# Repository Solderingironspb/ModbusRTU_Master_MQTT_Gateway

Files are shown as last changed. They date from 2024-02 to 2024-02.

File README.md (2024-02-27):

# ModbusRTU_Master_MQTT_Gateway
Данное устройство выступает мастером сети ModbusRTU. Обменивается данными с подчиненными устройствами (до 247 устройств на линии RS485). Все данные дублируются по MQTT на сервер, где они могут обрабатываться, а также появится возможность с сервера управлять подчиненными устройствами. (При условии, что ты это все в силах сам запрограммировать, мой друг...).

### Описание:
Общение осуществляется по RS485. Согласно документации, длина линии может доходить до 1 км, а изоляция по RS485 достигает 3000 В. На этой линии могут находиться счетчики электрической энергии, промышленные холодильники, климатические камеры, кондиционеры, щиты управления чего-либо и много чего другого. ModbusRTU используется с 1979 года по сей день и промышленных устройств, поддерживающих этот протокол миллионы.

### Немного по технической части:
Основную задачу по работе с ModbusRTU берет на себя RISC-V микроконтроллер CH32V203F8P6. На нем заданы тайминги для правильной работы протокола и написана своя реализация ModbusRTU Master. Все написано на RVMSIS. Отличный, очень компактный камушек с двумя UART на борту. Единственный минус данного МК - он не имеет входа кварцевого резонатора, поэтому сильно задирать скорость UART не стал бы. Обычного 9600 - 115200 хватит. Пока тестирую на 9600. Работает без сбоев.
По части WIFI - здесь распаян WiFi модуль на базе однокристальной системы (SoC) ESP8266. Написано свое ПО для модуля, что оно работает в качестве WIFI MQTT шлюза. Общение с CH32V203F8P6 происходит через USART по самописному протоколу, которым я пользуюсь уже 3 года без сбоев.
Многие, кто в теме задаст очередной вопрос, почему всю работу не осуществить на ESP8266? Отвечаю: я не знаю на столько хорошо ES8266, чтоб доверить ей работу с прерываниями, таймерами и прочим. Система, по которой я работаю - обкатана годами. Менять пока не собираюсь.

### По корпусу:
Очень хотелось выпендриться и уместить все в корпус на DIN рейку и чтоб 1 модуль занимало всего лишь. Из за этого мы видим антенну, которая немного мешает подключать RS485 (GND), но опять же....как часто мы GND туда подцепляем?) На 80% устройств она отсутствует в принципе.
DCDC преобразователем, чтоб можно было питать устройство от 12-24В тоже пришлось пожертвовать, негде его там расположить внутри). Поэтому питание устройства от 5В. Защита от переполюсовки присутствует.
Не знал, как поступить с портом для программирования устройства. На лицевую сторону тяжело уже было вывести, поэтому ничего не оставалось, как сделать окошко в корпусе справа. Открыл - запрогал - закрыл.

### По дизайну:
Все в традициях нашего оборудования) Немного уродливо, зато с душой и относительно бюджетно 😁

### Ну и не забываем, что все делалось в домашних условиях)











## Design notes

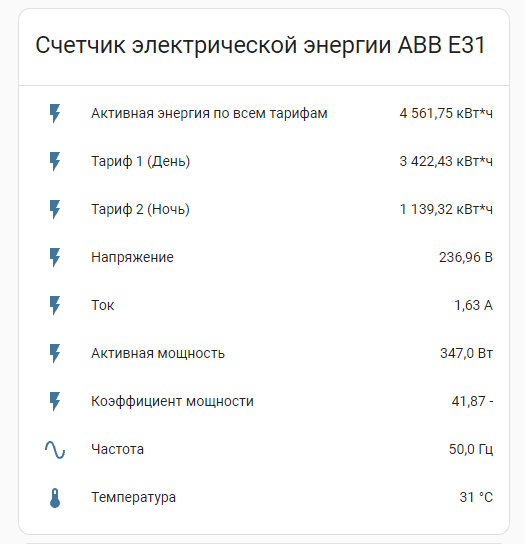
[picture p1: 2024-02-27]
Project1_Опрос_электросчетчика_ABB_E31/Снимок.PNG

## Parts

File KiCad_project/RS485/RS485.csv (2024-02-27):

Source: | Z:\KiCad_project\RS485\RS485\RS485.kicad_sch
Date: | 03.02.2024 23:45:19
Tool: | Eeschema 7.0.8
Generator: | C:\Program Files\KiCad\7.0\bin\scripting\plugins/bom_csv_grouped_by_value.py
Component Count: | 59
Collated Components:
Item | Qty | Reference(s) | Value | LibPart | Footprint | Datasheet | DNP
1 | 4 | C1, C5, C6, C8 | 100n | Device:C_Small | Capacitor_SMD:C_0603_1608Metric | ~
2 | 1 | C2 | 10uF | Device:C_Small | Capacitor_SMD:C_0805_2012Metric | ~
3 | 2 | C3, C4 | 5uF | Device:C_Small | Capacitor_SMD:C_0805_2012Metric | ~
4 | 2 | C7, C9 | 220pF | Device:C_Small | Capacitor_SMD:C_0805_2012Metric | ~
5 | 4 | C10, C11, C14, C15 | 47uF | Device:C_Polarized_Small | Capacitor_Tantalum_SMD:CP_EIA-3528-21_Kemet-B_Pad1.50x2.35mm_HandSolder | ~
6 | 3 | C12, C13, C16 | 100nF | Device:C_Small | Capacitor_SMD:C_0603_1608Metric | ~
7 | 1 | CA-IS3741LW1 | ~ | CA-IS374x:CA-IS3741LW | Package_SO:SOIC-16W_7.5x10.3mm_P1.27mm
8 | 1 | CH32V203F8P1 | ~ | CH32V:CH32V203F8P6 | Package_SO:SSOP-20_5.3x7.2mm_P0.65mm
9 | 1 | D1 | PSM712-LF-T7 | Device:D_TVS_Dual_AAC | Package_TO_SOT_SMD:SOT-23-3 | ~
10 | 1 | D2 | Tx2 | Device:LED | Diode_SMD:D_0805_2012Metric | ~
11 | 1 | D3 | Rx2 | Device:LED | Diode_SMD:D_0805_2012Metric | ~
12 | 1 | D4 | 10MQ100NPBF | Diode:B120-E3 | Diode_SMD:D_SMA | http://www.vishay.com/docs/88946/b120.pdf
13 | 1 | D5 | LED | Device:LED | Diode_SMD:D_0805_2012Metric | ~
14 | 1 | D6 | Rx1 | Device:LED | Diode_SMD:D_0805_2012Metric | ~
15 | 1 | D7 | Tx1 | Device:LED | Diode_SMD:D_0805_2012Metric | ~
16 | 1 | D8 | Wifi | Device:LED | Diode_SMD:D_0805_2012Metric | ~
17 | 2 | J1, J2 | Master/Slave | Connector:Conn_01x03_Pin | Connector_PinHeader_2.54mm:PinHeader_1x03_P2.54mm_Vertical | ~
18 | 1 | J3 | Debug | Connector:Conn_01x04_Pin | Connector_PinHeader_2.54mm:PinHeader_1x04_P2.54mm_Vertical | ~
19 | 1 | J4 | Conn_01x02_Pin | Connector:Conn_01x02_Pin |  | ~
20 | 1 | L1 | 22uH | Device:L_Small | Inductor_SMD:L_1210_3225Metric | ~
21 | 1 | PS1 | MornsunS0505SC | Converter_DCDC:MEE1S0505SC | Converter_DCDC:Converter_DCDC_Murata_MEE1SxxxxSC_THT | https://power.murata.com/pub/data/power/ncl/kdc_mee1.pdf
22 | 1 | Q1 | IRLML0060 | Transistor_FET:IRLML0030 | Package_TO_SOT_SMD:SOT-23 | https://www.infineon.com/dgdl/irlml0030pbf.pdf?fileId=5546d462533600a401535664773825df
23 | 1 | R1 | 240 | Device:R_Small | Resistor_SMD:R_0805_2012Metric | ~
24 | 2 | R2, R11 | 470R | Device:R_Small | Resistor_SMD:R_0805_2012Metric | ~
25 | 8 | R3, R7, R16, R17, R18, R19, R20, R21 | 10k | Device:R_Small | Resistor_SMD:R_0603_1608Metric | ~
26 | 2 | R4, R8 | 10R | Device:R_Small | Resistor_SMD:R_0805_2012Metric | ~
27 | 2 | R5, R9 | 100R | Device:R_Small | Resistor_SMD:R_0805_2012Metric | ~
28 | 6 | R6, R10, R12, R13, R14, R15 | 1k | Device:R_Small | Resistor_SMD:R_0603_1608Metric | ~
29 | 1 | SW1 | Reset | Switch:SW_MEC_5G | Button_Switch_SMD:SW_Push_1P1T_NO_CK_KSC6xxJ | http://www.apem.com/int/index.php?controller=attachment&id_attachment=488
30 | 1 | U1 | MAX485E | Interface_UART:MAX485E | Package_SO:SO-8_3.9x4.9mm_P1.27mm | https://datasheets.maximintegrated.com/en/ds/MAX1487E-MAX491E.pdf
31 | 2 | U2, U4 | AMS1117-3.3 | Regulator_Linear:AMS1117-3.3 | Package_TO_SOT_SMD:SOT-223-3_TabPin2 | http://www.advanced-monolithic.com/pdf/ds1117.pdf
32 | 1 | U3 | ESP-07 | RF_Module:ESP-07 | RF_Module:ESP-07 | http://wiki.ai-thinker.com/_media/esp8266/esp8266_series_modules_user_manual_v1.1.pdf

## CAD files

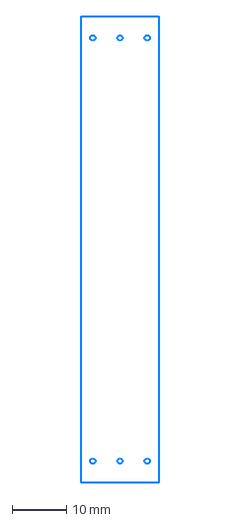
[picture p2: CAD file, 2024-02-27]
KiCad_project/RS485/KOMPAS3D/1.dxf
14.3 x 86.0 mm

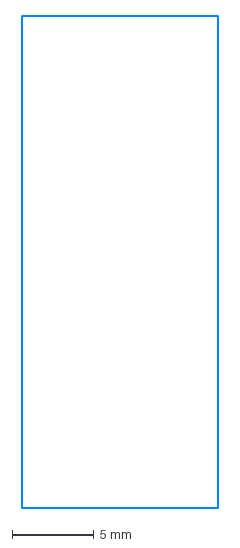
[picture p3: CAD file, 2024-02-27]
KiCad_project/RS485/KOMPAS3D/3.dxf
12.0 x 30.0 mm

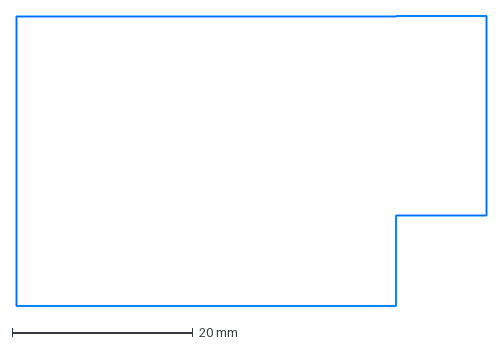
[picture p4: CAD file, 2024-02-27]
KiCad_project/RS485/KOMPAS3D/2.dxf
52.0 x 32.0 mm

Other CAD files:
KiCad_project/RS485/KOMPAS3D/1.dwg
KiCad_project/RS485/KOMPAS3D/2.dwg
KiCad_project/RS485/KOMPAS3D/3.dwg

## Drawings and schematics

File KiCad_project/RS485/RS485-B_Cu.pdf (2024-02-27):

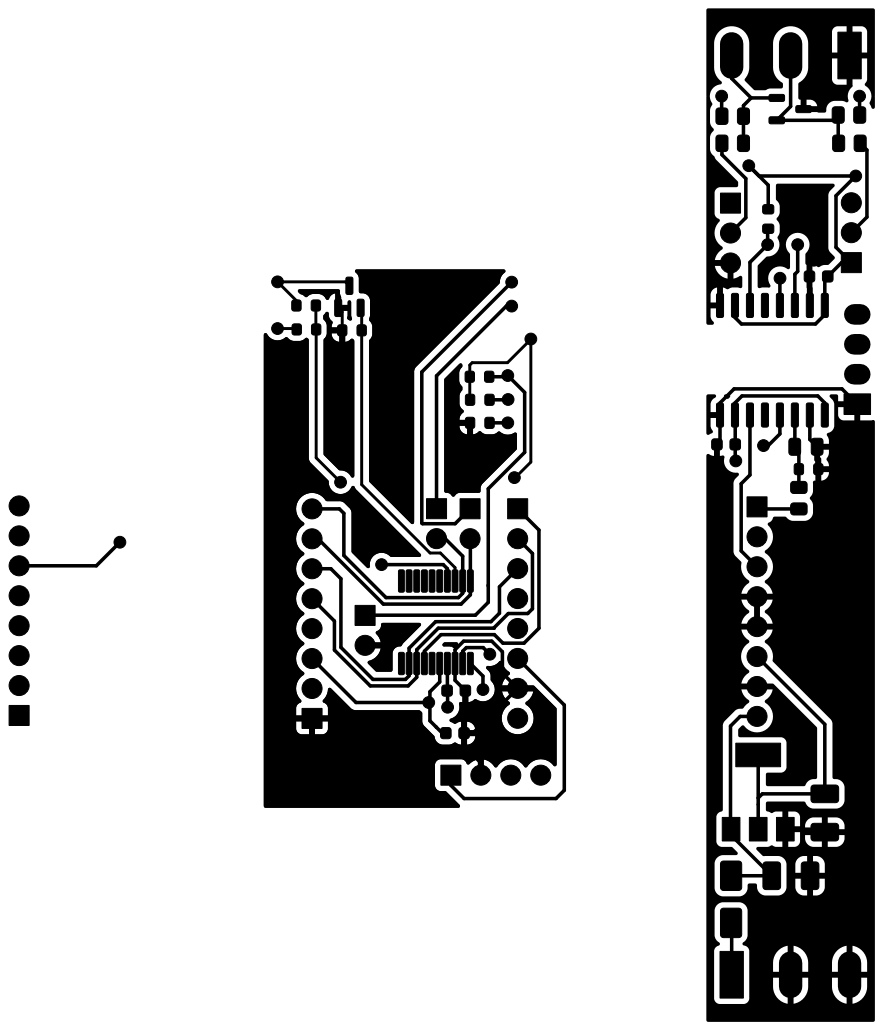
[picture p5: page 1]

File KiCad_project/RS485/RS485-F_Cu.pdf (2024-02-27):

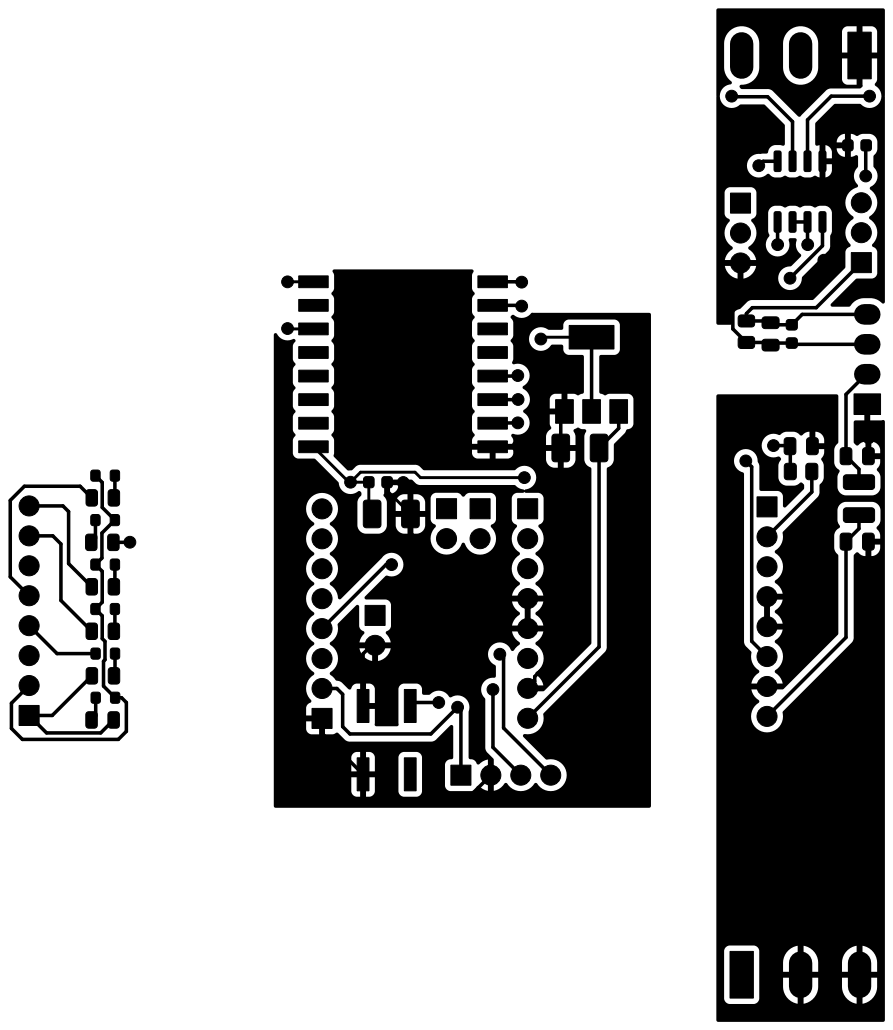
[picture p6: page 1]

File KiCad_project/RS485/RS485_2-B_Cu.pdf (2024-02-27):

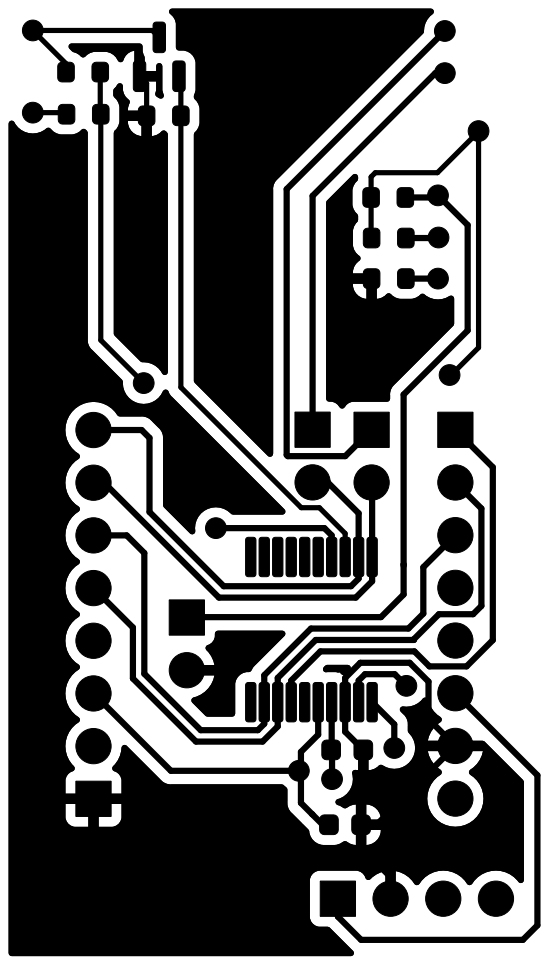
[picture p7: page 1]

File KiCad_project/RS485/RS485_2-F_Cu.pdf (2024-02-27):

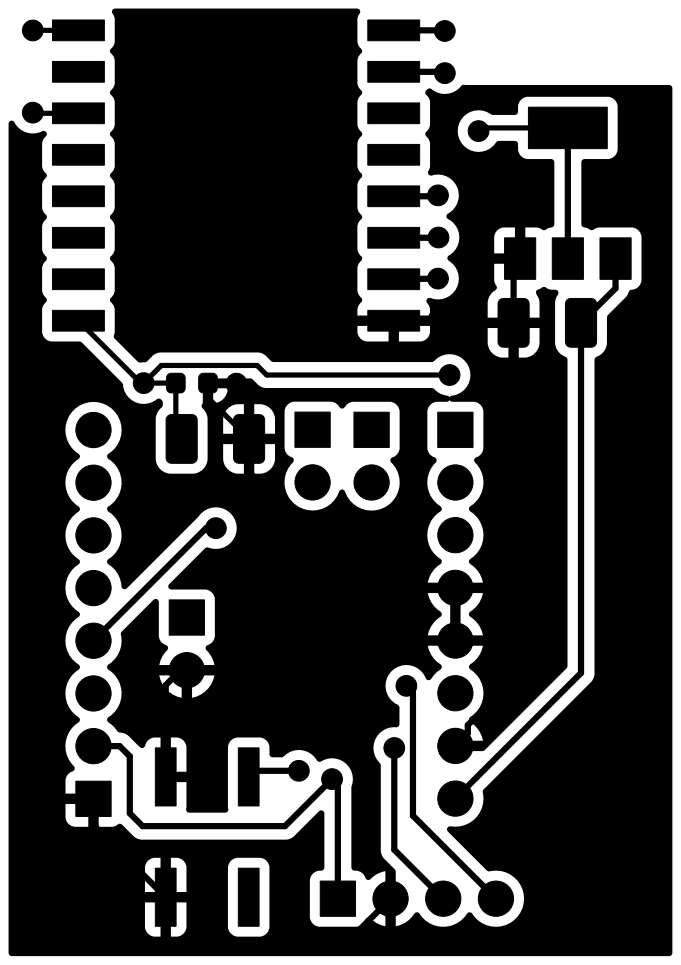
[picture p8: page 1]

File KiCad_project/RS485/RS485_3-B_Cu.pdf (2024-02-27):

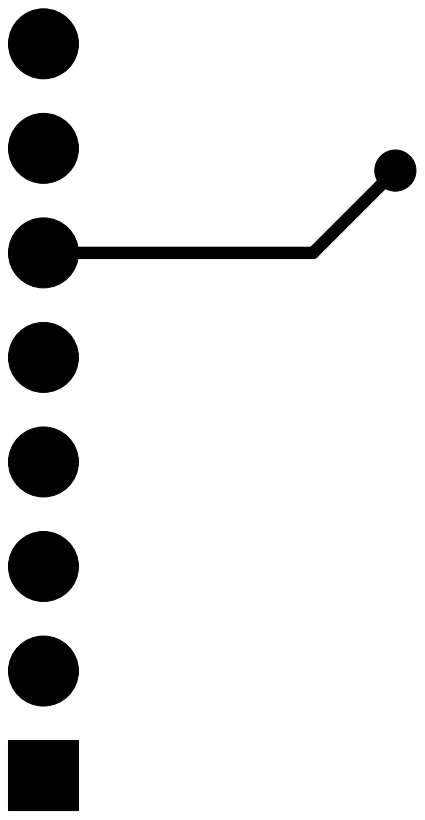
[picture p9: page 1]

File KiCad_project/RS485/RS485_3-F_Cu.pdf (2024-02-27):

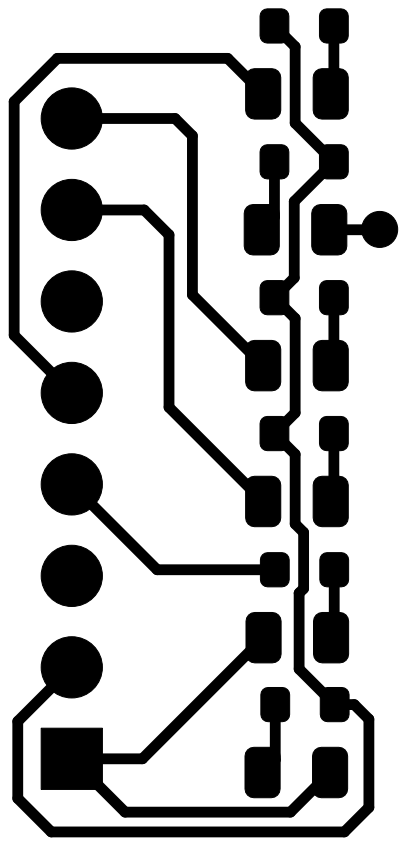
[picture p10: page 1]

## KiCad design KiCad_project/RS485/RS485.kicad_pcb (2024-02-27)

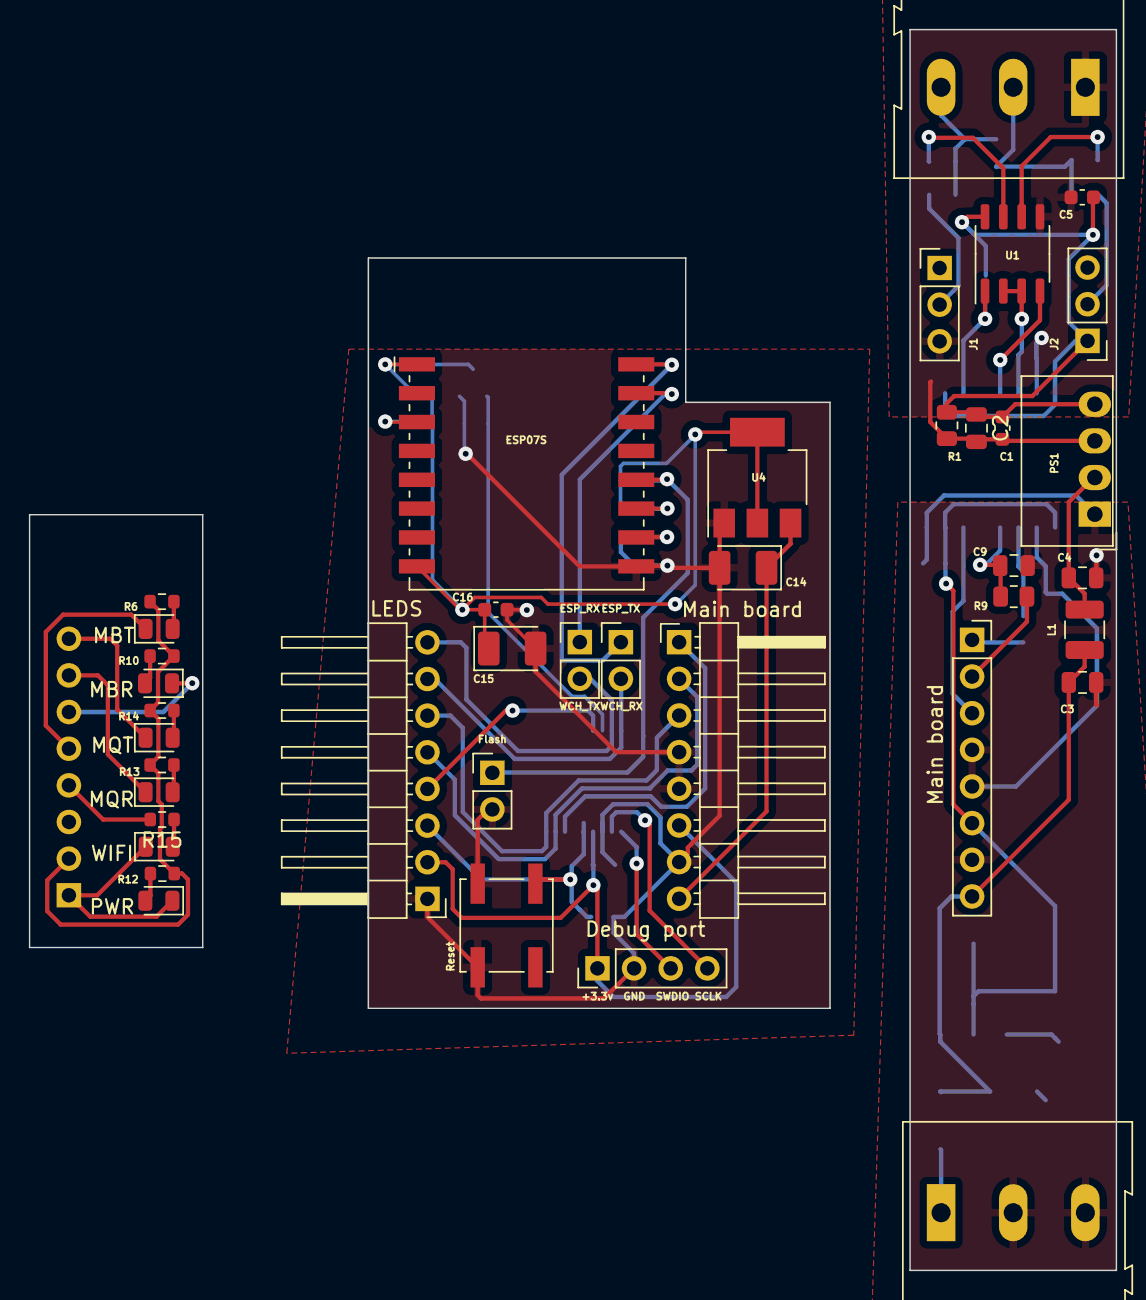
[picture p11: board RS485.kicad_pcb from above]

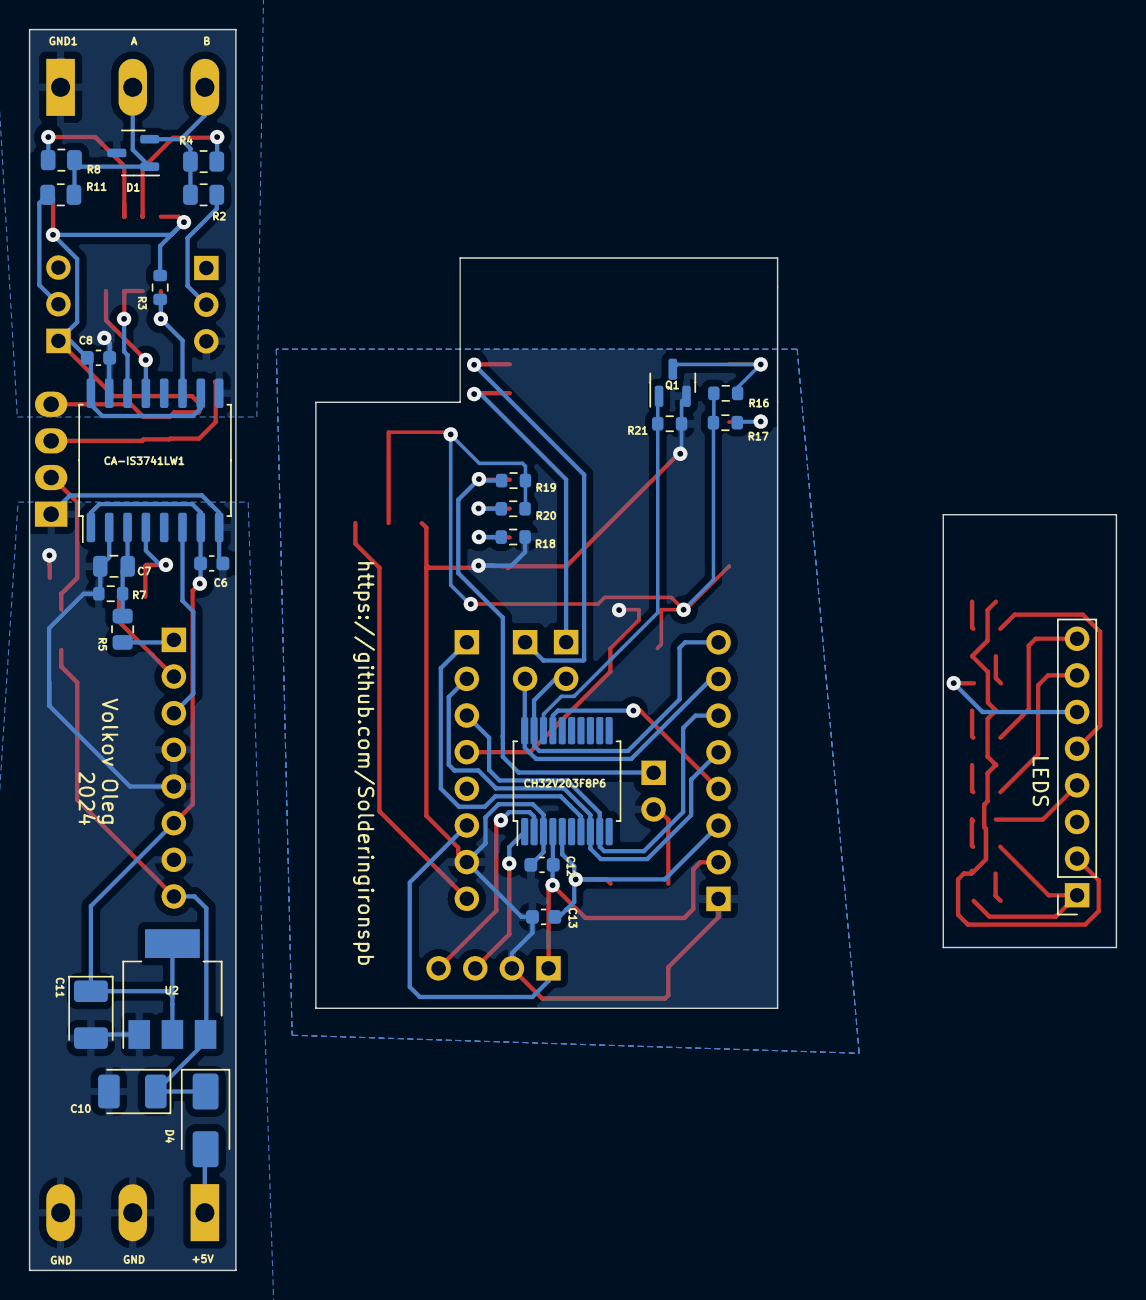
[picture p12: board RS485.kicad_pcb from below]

Board: 2 copper layers, 75.3 x 86.0 mm, 65 parts (27 on the bottom side), 41 nets.

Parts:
C1, C5, C6, C8: 100n; C_0603_1608Metric
C2: 10uF; C_0805_2012Metric
C3, C4: 5uF; C_0805_2012Metric
C7, C9: 220pF; C_0805_2012Metric
C10, C11, C14, C15: 47uF; CP_EIA-3528-21_Kemet-B_Pad1.50x2.35mm_HandSolder
C12, C13, C16: 100nF; C_0603_1608Metric
CA-IS3741LW1: SOIC-16W_7.5x10.3mm_P1.27mm
CH32V203F8P6: SSOP-20_5.3x7.2mm_P0.65mm
D1: PSM712-LF-T7; SOT-23-3
D4: 10MQ100NPBF; D_SMA
Debug port: Debug; PinHeader_1x04_P2.54mm_Vertical
ESP07S: ESP-07
ESP_RX: PinHeader_1x02_P2.54mm_Vertical
ESP_TX: PinHeader_1x02_P2.54mm_Vertical
Flash: PinHeader_1x02_P2.54mm_Vertical
J1, J2: Master/Slave; PinHeader_1x03_P2.54mm_Vertical
L1: 22uH; L_1210_3225Metric
LEDS: PinHeader_1x08_P2.54mm_Horizontal
LEDS#2: PinSocket_1x08_P2.54mm_Vertical
MBR: Rx2; D_0805_2012Metric
MBT: Tx2; D_0805_2012Metric
MQR: Rx1; D_0805_2012Metric
MQT: Tx1; D_0805_2012Metric
Main board: PinHeader_1x08_P2.54mm_Horizontal
Main board#2: PinSocket_1x08_P2.54mm_Vertical
PS1: MornsunS0505SC; Converter_DCDC_Murata_MEE1SxxxxSC_THT
PWR: LED; D_0805_2012Metric
Q1: IRLML0060; SOT-23
R1: 240; R_0805_2012Metric
R2, R11: 470R; R_0805_2012Metric
R3, R7, R16, R17, R18, R19, R20, R21: 10k; R_0603_1608Metric
R4, R8: 10R; R_0805_2012Metric
R5, R9: 100R; R_0805_2012Metric
R6, R10, R12, R13, R14, R15: 1k; R_0603_1608Metric
Reset: Reset; SW_Push_1P1T_NO_CK_KSC6xxJ
U1: MAX485E; SO-8_3.9x4.9mm_P1.27mm
U2, U4: AMS1117-3.3; SOT-223-3_TabPin2
WIFI: Rx1; D_0805_2012Metric

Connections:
+3.3V: C15.1, C16.1, ESP07S.8 (VCC), R16.1, R17.1, R19.1, R20.1, U4.2 (VO)
+3V3: C6.1, C11.1, C12.1, CA-IS3741LW1.1 (VDDA), CA-IS3741LW1.7 (ENA), CH32V203F8P6.4 (VDD), Debug port.1, LEDS.2, LEDS#2.2, Main board.6, Main board#2.6, R6.1, R10.1, R12.1, R13.2, R14.2, U2.2 (VO)
+5V: C3.1, C10.1, C14.1, D4.1 (K), L1.1, Main board.8, Main board#2.8, U2.3 (VI), U4.3 (VI)
A: D1.1 (A1), R8.2, R11.1
B: D1.2 (A2), R2.2, R4.2
ESP_UART_Rx: ESP07S.15 (GPIO3/RXD), ESP_RX.1
ESP_UART_Tx: ESP07S.16 (GPIO1/TXD), ESP_TX.1
GND: C3.2, C4.2, C6.2, C7.2, C9.2, C10.2, C11.2, C12.2, C13.2, C14.2, C15.2, C16.2, CA-IS3741LW1.2 (GNDA), CA-IS3741LW1.8 (GNDA), CH32V203F8P6.3 (VSS), Debug port.2, ESP07S.9 (GND), Flash.2, LEDS.1, LEDS#2.1, Main board.4, Main board.5, Main board.7, Main board#2.4, Main board#2.5, Main board#2.7, PS1.1 (-Vin), PWR.1 (K), Q1.2 (S), R7.2, R18.2, R21.2, Reset.1 (A), U2.1 (GND), U4.1 (GND), WIFI.1 (K)
GND1: C1.2, C2.2, C5.2, C8.2, CA-IS3741LW1.9 (GNDB), CA-IS3741LW1.15 (GNDB), D1.3 (common), J1.3, PS1.3 (-Vout), R1.2, U1.5 (GND)
unnamed: C7.1, CA-IS3741LW1.3 (VI1), R5.2, R7.1
unnamed: C9.1, CA-IS3741LW1.4 (VI2), R9.2
unnamed: CA-IS3741LW1.11 (VI4), R3.2, U1.1 (RO)
unnamed: CA-IS3741LW1.14 (VO1), U1.2 (~RE), U1.3 (DE)
unnamed: CA-IS3741LW1.13 (VO2), U1.4 (DI)
unnamed: C13.1, CH32V203F8P6.5 (NRST), LEDS.3, LEDS#2.3, Reset.2 (A)
unnamed: CH32V203F8P6.17 (PB15), LEDS.4, LEDS#2.4, R15.2
unnamed: MBT.2 (A), R6.2
unnamed: MBR.2 (A), R10.2
unnamed: PWR.2 (A), R12.2
unnamed: MQR.2 (A), R13.1
unnamed: MQT.2 (A), R14.1
unnamed: R15.1, WIFI.2 (A)
unnamed: J1.2, R2.1
unnamed: J2.2, R11.2
unnamed: C4.1, L1.2, PS1.2 (+Vin)
unnamed: ESP07S.1 (~RST), Q1.3 (D), R16.2
unnamed: R8.1, U1.6 (A)
unnamed: R4.1, U1.7 (B)
unnamed: ESP07S.3 (EN), R17.2
unnamed: ESP07S.12 (GPIO0), Flash.1, R19.2
unnamed: ESP07S.11 (GPIO2), R20.2
unnamed: ESP07S.10 (GPIO15), R18.1
PA8: CH32V203F8P6.18 (PA8), Q1.1 (G), R21.1
PA9: CH32V203F8P6.19 (PA9), ESP_RX.2, LEDS.8, LEDS#2.8, MQT.1 (K)
PA10: CH32V203F8P6.20 (PA10), ESP_TX.2, LEDS.7, LEDS#2.7, MQR.1 (K)
RO/DI: CH32V203F8P6.7 (PA1), Main board.1, Main board#2.1, R5.1
Rx: CA-IS3741LW1.6 (VO4), CH32V203F8P6.9 (PA3), LEDS.6, LEDS#2.6, MBR.1 (K), Main board.3, Main board#2.3
SCLK: CH32V203F8P6.2 (PB7), Debug port.4
SWDIO: CH32V203F8P6.1 (PB6), Debug port.3
Tx: CH32V203F8P6.8 (PA2), LEDS.5, LEDS#2.5, MBT.1 (K), Main board.2, Main board#2.2, R9.1
VDDB: C1.1, C2.1, C5.1, C8.1, CA-IS3741LW1.10 (ENB), CA-IS3741LW1.16 (VDDB), J2.1, PS1.4 (+Vout), R1.1, R3.1, U1.8 (VCC)

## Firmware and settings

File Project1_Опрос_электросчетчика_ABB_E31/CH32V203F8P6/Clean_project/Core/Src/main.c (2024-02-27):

/* CH32V203F8P6 ModbusRTU Master
 * ESP8266 UART to MQTT transmitter
 * Debug:
 * PB6 - SWDIO
 * PB7 - SWCLK
 * USART2 - ModbusRTU(RS485):
 * PA1 - RO/DI
 * PA2 - Tx2
 * PA3 - Rx2
 * USART1 - ESP8266
 * PA9 - Tx1
 * PA10 -Rx1
 * */

#include "main.h"
#include "stdio.h"
#include <stdbool.h>
#include "ESP8266_lib.h"
#include "MQTT.h"
#include "SoftwareTimer.h"

extern struct USART_name husart1; //Объявляем структуру по USART.(см. ch32v203x_RVMSIS.h)
extern uint8_t NETWORK_Status;
uint8_t MQTT_Arr[64] = { 0, };

extern float ABB_E31_Total_active_energy;       //01
extern float ABB_E31_Active_energy_1;           //02
extern float ABB_E31_Active_energy_2;           //03
extern float ABB_E31_Active_energy_3;           //04
extern float ABB_E31_Active_energy_4;           //05
extern float ABB_E31_Voltage;                      //06
extern float ABB_E31_Amp;                          //07
extern float ABB_E31_Active_power;                 //08
extern float ABB_E31_Power_factor;                 //09
extern float ABB_E31_Frequency;                    //10
extern int16_t ABB_E31_Temperature;                //11

extern bool flags_tx_data_ready[64];
//extern bool flags_read_data_block[64];

/*====================================Добавить в main.c====================================*/
uint32_t ModbusRTU_Timeout = 0; //Таймаут для ответов
uint32_t ModbusRTU_delay_between_pool = 0; //Задержка между фреймами
volatile uint8_t ModbusRTU_Counter_in_queue = 0; //Счетчик запросов в отчереди на отправку слейв устройствам. Номер счетчика соответствует отправленному запросу.
bool flag_ModbusRTU_request_on = true; //флаг, разрешающий отправку пакета
bool flag_ModbusRTU_block = false; //флаг, блокирующий работу мастера, пока не обработается входящее сообщение
/*====================================Добавить в main.c====================================*/

bool Task1 = false;
uint32_t MQTT_Send_Timer; //Таймер для отправки MQTT

void Task1_MQTT_Send(void) {
    if (NETWORK_Status == MQTT_STATUS_CONNECTED) {
        if (flags_tx_data_ready[0]) {
            UART_MQTT_Send_data_float(1, ABB_E31_Total_active_energy, MQTT_Arr);
            UART_MQTT_Send_data_float(2, ABB_E31_Active_energy_1, MQTT_Arr);
            UART_MQTT_Send_data_float(3, ABB_E31_Active_energy_2, MQTT_Arr);
            UART_MQTT_Send_data_float(4, ABB_E31_Active_energy_3, MQTT_Arr);
            UART_MQTT_Send_data_float(5, ABB_E31_Active_energy_4, MQTT_Arr);
            UART_MQTT_Send_data_float(6, ABB_E31_Voltage, MQTT_Arr);
            UART_MQTT_Send_data_float(7, ABB_E31_Amp, MQTT_Arr);
            UART_MQTT_Send_data_float(8, ABB_E31_Active_power, MQTT_Arr);
            UART_MQTT_Send_data_float(9, ABB_E31_Power_factor, MQTT_Arr);
            UART_MQTT_Send_data_float(10, ABB_E31_Frequency, MQTT_Arr);
            flags_tx_data_ready[0] = false;
        }
        if (flags_tx_data_ready[1]){
            UART_MQTT_Send_data_int16_t(11, ABB_E31_Temperature, MQTT_Arr);
            flags_tx_data_ready[1] = false;
        }
    }
}

void MQTT_Reveieve(void) {
    switch (husart1.rx_buffer[1]) {
//    case 18:
//        OWEN_PR200_Out3 = UART_MQTT_Receive_data_int16_t(husart1.rx_buffer);
//        flags_read_data_block[4] = true;
//        break;
//    case 19:
//        OWEN_PR200_Out4 = UART_MQTT_Receive_data_int16_t(husart1.rx_buffer);
//        flags_read_data_block[5] = true;
//        break;
    }
}

int main(void) {
    RVMSIS_Debug_init(); //Настройка дебага
    RVMSIS_RCC_SystemClock_144MHz(); //Настройка системной частоты.
    RVMSIS_SysTick_Timer_init(); //Настройка системного таймера на 1000 Гц.
    RVMSIS_USART2_Init(); //Настройка USART2 ModbusRTU 9600 8N1
    RVMSIS_USART1_Init(); //Настройка USART1 9600 8N1
    RVMSIS_GPIO_init(GPIOA, 1, GPIO_GENERAL_PURPOSE_OUTPUT, GPIO_OUTPUT_PUSH_PULL, GPIO_Speed_50MHz); //Настройка ножки RO/DI
    MODBUSRTU_RECEIEVE;
    RVMSIS_GPIO_init(GPIOA, 8, GPIO_GENERAL_PURPOSE_OUTPUT, GPIO_OUTPUT_PUSH_PULL, GPIO_Speed_50MHz); //ножка RESET ESP8266
    RVMSIS_GPIO_init(GPIOB, 15, GPIO_GENERAL_PURPOSE_OUTPUT, GPIO_OUTPUT_PUSH_PULL, GPIO_Speed_50MHz); //Wifi status
    RVMSIS_TIM3_init();
    ESP8266_Reset(200);

    Delay_ms(5); //Перед началой основного цикла сделаем задержку, чтоб не лез всякий мусор.

    while(1) {

        /*Выполнение работы ModbusRTU*/
        ModbusRTU_Master_pool_run();
        /*Выполнение работы ModbusRTU*/

        /*Работа индикации подключения к WIFI и MQTT*/
        ESP8266_Indication_run();
        /*Работа индикации подключения к WIFI и MQTT*/

        /*Отправка данных по MQTT*/
        if (Task1) {
            Task1_MQTT_Send();
            Task1 = false;
            Software_timer((uint32_t*) &MQTT_Send_Timer, 2000);
        }
        /*Отправка данных по MQTT*/

    }
}

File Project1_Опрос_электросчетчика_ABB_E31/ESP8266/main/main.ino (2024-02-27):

/**
 ******************************************************************************
 @file           : main.cpp
 @brief          : Main program body
 ******************************************************************************
 @attention

 Created on: 05 мая. 2023 г.
 Author: Oleg Volkov

 YouTube: https://www.youtube.com/channel/UCzZKTNVpcMSALU57G1THoVw
 GitHub: https://github.com/Solderingironspb/Lessons-Stm32/blob/master/README.md
 Группа ВК: https://vk.com/solderingiron.stm32

 ******************************************************************************
 */

#include <ESP8266WiFi.h>
#include <PubSubClient.h>
#include "uart_mqtt_lib.h"

#define VARIABLE_ID esp_rx_buffer[1]

#define name_mqtt_user "ABB_E31"


/*-------------------------------Настройки Wi-fi------------------------------------------*/

uint8_t newMACAddress[] = { 0x32, 0xAE, 0x11, 0x07, 0x0D, 0x70 }; //Задаем MAC адрес устройства

const char *ssid = "****";       // Имя Wi-fi точки доступа
const char *pass = "****";  // Пароль от Wi-fi точки доступа

const char *mqtt_server = "192.168.0.104";  // Имя сервера MQTT
const int mqtt_port = 1883;                       // Порт для подключения к серверу MQTT
const char *mqtt_user = "****";                // Логин от сервера
const char *mqtt_pass = "****";            // Пароль от сервера

/*-------------------------------Настройки Wi-fi------------------------------------------*/

uint8_t esp_rx_buffer[128] = { 0, };  //входящий буфер
uint8_t esp_tx_buffer[128] = { 0, };  //исходящий буфер

float ABB_E31_Total_active_energy;       //01
float ABB_E31_Active_energy_1;           //02
float ABB_E31_Active_energy_2;           //03
float ABB_E31_Active_energy_3;           //04
float ABB_E31_Active_energy_4;           //05
float ABB_E31_Voltage;                      //06
float ABB_E31_Amp;                          //07
float ABB_E31_Active_power;                 //08
float ABB_E31_Power_factor;                 //09
float ABB_E31_Frequency;                    //10
int16_t ABB_E31_Temperature;                //11          


WiFiClient wclient;
PubSubClient client( wclient, mqtt_server, mqtt_port);

/* USER CODE BEGIN PFP */
void callback(const MQTT::Publish &pub);
void uart_parsing(void);
/* USER CODE END PFP */

// Функция получения данных от сервера
void callback(const MQTT::Publish &pub) {
  String payload = pub.payload_string();

  /*------------------Парсинг приходящих писем в топики-----------------------*/
  /*if (String(pub.topic()) == "Test/OWEN_PR200_Out3")  //  проверяем из нужного ли нам топика пришли данные
  {
    OWEN_PR200_Out3 = payload.toInt();  //  преобразуем полученные данные в тип float(все типы данных, кроме float преобразуем в integer)
    UART_MQTT_Send_data_uint16_t(18, OWEN_PR200_Out3, esp_tx_buffer);
  }
  if (String(pub.topic()) == "Test/OWEN_PR200_Out4")  //  проверяем из нужного ли нам топика пришли данные
  {
    OWEN_PR200_Out4 = payload.toInt();  //  преобразуем полученные данные в тип float(все типы данных, кроме float преобразуем в integer)
    UART_MQTT_Send_data_uint16_t(19, OWEN_PR200_Out4, esp_tx_buffer);
  }*/

  /*------------------Парсинг приходящих писем в топики-----------------------*/
}

void uart_parsing(void) {
  if (Serial.available() > 0) {
    Serial.readBytes(esp_rx_buffer, 9);
    switch (VARIABLE_ID) {
      /*----------------здесь будет выборка по номеру переменной-----------------------*/

      case (1):
      if (UART_MQTT_Checksumm_validation(esp_rx_buffer)) {
        ABB_E31_Total_active_energy = UART_MQTT_Receive_data_float(esp_rx_buffer);
        client.publish("ABB_E31/Total_active_energy", String(ABB_E31_Total_active_energy));
      }
      break;
      case (2):
      if (UART_MQTT_Checksumm_validation(esp_rx_buffer)) {
        ABB_E31_Active_energy_1 = UART_MQTT_Receive_data_float(esp_rx_buffer);
        client.publish("ABB_E31/Active_energy_1", String(ABB_E31_Active_energy_1));
      }
      break;
      case (3):
      if (UART_MQTT_Checksumm_validation(esp_rx_buffer)) {
        ABB_E31_Active_energy_2 = UART_MQTT_Receive_data_float(esp_rx_buffer);
        client.publish("ABB_E31/Active_energy_2", String(ABB_E31_Active_energy_2));
      }
      break;
      case (4):
      if (UART_MQTT_Checksumm_validation(esp_rx_buffer)) {
        ABB_E31_Active_energy_3 = UART_MQTT_Receive_data_float(esp_rx_buffer);
        client.publish("ABB_E31/Active_energy_3", String(ABB_E31_Active_energy_3));
      }
      break;
      case (5):
      if (UART_MQTT_Checksumm_validation(esp_rx_buffer)) {
        ABB_E31_Active_energy_4 = UART_MQTT_Receive_data_float(esp_rx_buffer);
        client.publish("ABB_E31/Active_energy_4", String(ABB_E31_Active_energy_4));
      }
      break;
      case (6):
      if (UART_MQTT_Checksumm_validation(esp_rx_buffer)) {
        ABB_E31_Voltage = UART_MQTT_Receive_data_float(esp_rx_buffer);
        client.publish("ABB_E31/Voltage", String(ABB_E31_Voltage));
      }
      break;
      case (7):
      if (UART_MQTT_Checksumm_validation(esp_rx_buffer)) {
        ABB_E31_Amp = UART_MQTT_Receive_data_float(esp_rx_buffer);
        client.publish("ABB_E31/Amp", String(ABB_E31_Amp));
      }
      break;
      case (8):
      if (UART_MQTT_Checksumm_validation(esp_rx_buffer)) {
        ABB_E31_Active_power = UART_MQTT_Receive_data_float(esp_rx_buffer);
        client.publish("ABB_E31/Active_power", String(ABB_E31_Active_power));
      }
      break;
      case (9):
      if (UART_MQTT_Checksumm_validation(esp_rx_buffer)) {
        ABB_E31_Power_factor = UART_MQTT_Receive_data_float(esp_rx_buffer);
        client.publish("ABB_E31/Power_factor", String(ABB_E31_Power_factor));
      }
      break;
      case (10):
      if (UART_MQTT_Checksumm_validation(esp_rx_buffer)) {
        ABB_E31_Frequency = UART_MQTT_Receive_data_float(esp_rx_buffer);
        client.publish("ABB_E31/Frequency", String(ABB_E31_Frequency));
      }
      break;
      case (11):
      if (UART_MQTT_Checksumm_validation(esp_rx_buffer)) {
        ABB_E31_Temperature = UART_MQTT_Receive_data_int16_t(esp_rx_buffer);
        client.publish("ABB_E31/Temperature", String(ABB_E31_Temperature));
      }
      break;
      
      /*----------------здесь будет выборка по номеру переменной-----------------------*/
    }
    memset(esp_rx_buffer, 0, 9);  //очистка входящего буффера
  }
}

void setup(void) {

  Serial.begin(9600);
  delay(100);
  Serial.setTimeout(5);
  WiFi.disconnect(true);
  WiFi.mode(WIFI_STA);
  //wifi_set_macaddr(STATION_IF, &newMACAddress[0]);
  WiFi.hostname(name_mqtt_user);
  WiFi.begin(ssid, pass);

}
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

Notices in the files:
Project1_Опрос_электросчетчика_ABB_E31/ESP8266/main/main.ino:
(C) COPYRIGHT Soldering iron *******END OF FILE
